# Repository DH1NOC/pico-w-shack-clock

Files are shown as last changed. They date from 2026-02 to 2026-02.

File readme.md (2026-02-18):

# Shack Präzisions-Weltzeituhr (Pico W)

Eine hochpräzise Amateurfunk-Stationsuhr auf Basis des Raspberry Pi Pico W. Sie kombiniert Internet-Zeit (NTP) mit einem temperaturkompensierten Echtzeit-Modul (DS3231) und visualisiert die Lokalzeit (MEZ/MESZ) sowie UTC parallel auf einem 2004 LCD-Display.

## Motivation & Konzept

Klassische Funkuhren auf **DCF77-Basis** stoßen in modernen Umgebungen oft an ihre Grenzen:

* **Empfangsprobleme:** Ferritstab-Antennen sind richtungsempfindlich; Signale werden in Gebäuden stark gedämpft.
* **Störanfälligkeit:** Schaltnetzteile, PCs und LED-Beleuchtung stören das Langwellensignal massiv.
* **Trägheit:** Ein vollständiger Zeitabgleich dauert nach dem Einschalten oft mehrere Minuten.
* **Fehlende UTC:** Handelsübliche Uhren zeigen meist nur die Lokalzeit, für den Funkbetrieb ist UTC jedoch essenziell.

**Die Lösung:**
Diese Uhr nutzt primär **NTP über WLAN** für die Genauigkeit und ein **RTC-Modul** für die Ausfallsicherheit.

* **Präzision:** Durch WLAN-Latenzen und MicroPython-Verarbeitung kann technisch ein Offset von ca. ±300ms auftreten. Dies ist für die visuelle Anzeige im Shack völlig akzeptabel.
* **Modularität:** Das integrierte GPS-Modul (GY-NEO6MV2) sorgt für Stratum-0-Präzision unabhängig vom Internet und ermöglicht die Anzeige des QTH-Locators.

---

## Hardware & Kosten

Die Gesamtkosten für das Projekt belaufen sich auf ca. **17€**.

### Teileliste

* **Mikrocontroller:** [Raspberry Pi Pico W (RP2040 WLAN)](https://www.berrybase.de/raspberry-pi-pico-w-rp2040-wlan-mikrocontroller-board)
* **GPS-Modul:** [u-blox NEO-6M / GY-NEO6MV2](https://amzn.eu/d/09GwwA2j)
* **RTC-Modul:** [DS3231 Real-Time Clock für Raspberry Pi](https://www.berrybase.de/ds3231-real-time-clock-modul-fuer-raspberry-pi)
* **Display (20x4 LCD mit I2C):**
* [Variante Weiß auf Blau](https://amzn.eu/d/08oH278n) oder
* [Variante Schwarz auf Grün](https://amzn.eu/d/0eiIwK74)

### Gehäuse (3D-Druck)

Es stehen zwei STL-Dateien für den Gehäusedruck zur Verfügung. Das Design ist so optimiert, dass **keine Stützen** notwendig sind:

* `Case_Front.stl` (Frontseite für Display und Pico)
* `Case_Back.stl` (Rückseite)

---

## Features

* **Timing:** Millisekunden-genaue Synchronisierung via GPS (Prio 1) oder NTP (Prio 2) mit Latenz-Korrektur.
* **Redundanz:** Dreistufiges Fallback-System: GPS -> WLAN/NTP -> DS3231 RTC.
* **Auto-Reconnect:** Automatische Wiederherstellung von WLAN und GPS-Fix im Hintergrund.
* **Smart Display (4 Zeilen):**
* Zeile 1: Datum, Wochentag und Callsign (rechtsbündig).
* Zeile 2: Lokalzeit (MEZ/MESZ).
* Zeile 3: UTC-Zeit.
* Zeile 4: Quelle (GPS/WLAN/RTC), bei GPS zusätzlich Satellitenanzahl & QTH Locator.

* **GPS-Integration:** Automatische Zeitsynchronisation und Positionsbestimmung (QTH Locator).
* **Debug-Modus:** Erweiterte Diagnose-Informationen für GPS und Systemstatus aktivierbar.
* **Boot-Animation:** Custom-Grafik eines Sendemasts mit Funkwellen beim Start.
* **Stabilität:** Modifizierter LCD-Treiber verhindert fehlerhafte Zeichen bei Soft-Resets.

---

## Verkabelung (Pinout)

Verwendet wird der I2C-Bus 0 des Pico W.

| Komponente | Pin | Pico W Pin | Farbe (Vorschlag) | Hinweis |
| --- | --- | --- | --- | --- |
| **DS3231 (RTC)** | VCC | **Pin 36 (3V3 OUT)** | Rot | 3.3V Versorgung |
|  | GND | **Pin 38 (GND)** | Schwarz | Masse |
|  | SDA | **Pin 1 (GP0)** | Blau | I2C Daten |
|  | SCL | **Pin 2 (GP1)** | Gelb | I2C Takt |
| **LCD 2004** | VCC | **Pin 40 (VBUS)** | Rot | **5V** (für Kontrast!) |
|  | GND | **Pin 3 (GND)** | Schwarz | Masse |
|  | SDA | **Pin 1 (GP0)** | Blau | Parallel zur RTC |
|  | SCL | **Pin 2 (GP1)** | Gelb | Parallel zur RTC |
| **GPS (NEO-6M)** | VCC | **Pin 40 (VBUS)** | Rot | 3.3-5V |
|  | GND | **Pin 38 (GND)** | Schwarz | Masse |
|  | TX | **Pin 7 (GP5)** | Grün | An Pico RX |
|  | RX | **Pin 6 (GP4)** | Weiß | An Pico TX |

> **Wichtig:** SDA und SCL von Display und RTC werden parallel auf dieselben Pins am Pico geführt.

---

## Einrichtung & Installation

### Schritt 1: MicroPython Firmware installieren

1. Aktuelle `.uf2`-Datei für Pico W laden: [micropython.org](https://micropython.org/download/RPI_PICO_W/)
2. Pico mit gedrückter **BOOTSEL**-Taste per USB anschließen.
3. Datei auf das erscheinende Laufwerk kopieren.

### Schritt 2: Entwicklungsumgebung

1. [Thonny IDE](https://thonny.org/) installieren.
2. Unten rechts als Interpreter **MicroPython (Raspberry Pi Pico)** wählen.

### Schritt 3: Dateien übertragen

Folgende Dateien müssen auf den Pico geladen werden:

* `lcd_api.py`: Basis-Treiber.
* `pico_i2c_lcd.py`: Modifizierter Treiber mit Reset-Fix.
* `config.json`: Konfigurationsdatei für WLAN.
* `main.py`: Hauptprogramm.

---

## Konfiguration (`config.json`)

Mehrere Netzwerke können als Fallback hinterlegt werden.

```json
{
    "wifi": [
        {
            "ssid": "MEIN_WLAN",
            "password": "PASSWORT1"
        },
        {
            "ssid": "BACKUP_WLAN",
            "password": "PASSWORT2"
        }
    ],
    "ntp_server": "pool.ntp.org",
    "sync_interval_min": 60
}

```

---

## Bedienung & Betrieb

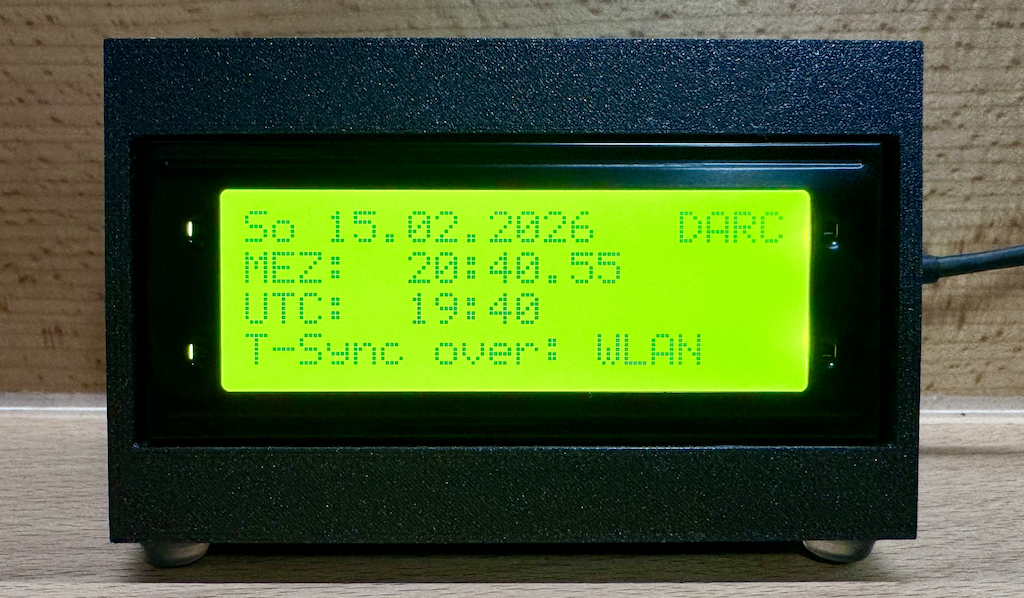
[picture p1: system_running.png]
System im Betrieb


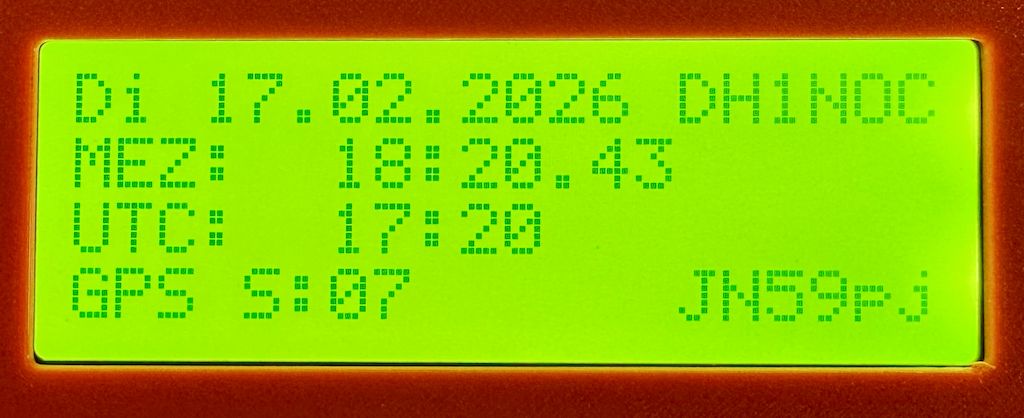
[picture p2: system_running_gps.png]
System im Betrieb mit GPS-Sync


1. **Start:** Strom anschließen (USB).
2. **Boot:** Die "DH1NOC CLOCK" Animation läuft (Sendemast strahlt Wellen ab).
3. **Betrieb:**
* Die Uhr startet sofort mit der Zeit aus dem **RTC-Modul** (Anzeige: `T-Sync over: RTC`).
* Im Hintergrund verbindet sie sich mit dem WLAN.
* Sobald verbunden, erfolgt der NTP-Abgleich. Die Anzeige wechselt auf `T-Sync over: WLAN`.
* Ein kleiner Stern `*` unten rechts signalisiert einen aktiven Abgleich.

4. **Ausfallsicherheit:** Sollte das WLAN ausfallen, läuft die Uhr präzise über das RTC-Modul weiter.

---

## Troubleshooting

* **Leeres Display:** Kontrast am blauen Potentiometer des I2C-Backpacks (Rückseite Display) justieren.
* **Kryptische Zeichen:** Pico kurz komplett stromlos machen (Hard Reset).
* **Falsche Stunde:** Die Zeitzone ist auf Deutschland fest voreingestellt. Prüfe die Funktion `get_cet_time_and_dst` in der `main.py`.

---

# Lizenz des Projekts

CC-BY-4.0
Dieses Projekt ist unter der [Creative Commons Attribution 4.0 International](https://creativecommons.org/licenses/by/4.0/deed.de) Lizenz lizenziert.

---

# Haftungsausschluss / Nutzung auf eigene Gefahr

Dieses Projekt wird ausschließlich zu Informations- und
Demonstrationszwecken bereitgestellt. Es handelt sich um ein
experimentelles Hobby- bzw. Entwicklungsprojekt und ausdrücklich **nicht
um ein geprüftes oder für den praktischen Einsatz geeignetes Produkt**.

Der Nachbau und die Nutzung erfolgen ausschließlich auf eigene
Verantwortung und Gefahr des Nutzers. Der Autor übernimmt keine Gewähr
für die Richtigkeit, Vollständigkeit, Funktionsfähigkeit oder Sicherheit
der bereitgestellten Informationen, Schaltungen, Software oder sonstigen
Inhalte.

## Haftung

Eine Haftung für Sachschäden, Vermögensschäden, Folgeschäden,
Produktionsausfälle, Datenverluste oder sonstige mittelbare Schäden ist
--- soweit gesetzlich zulässig --- ausgeschlossen.

## Fachkenntnisse erforderlich

Dieses Projekt richtet sich ausschließlich an Personen mit ausreichenden
Fachkenntnissen im Umgang mit Elektronik, elektrischen Anlagen und den
einschlägigen Sicherheitsvorschriften. Der Nutzer ist selbst
verantwortlich für die Einhaltung aller gesetzlichen Bestimmungen,
Normen und Sicherheitsanforderungen.

## Keine Produkthaftung

Es wird kein Produkt, keine Baugruppe und keine technische Lösung im
Sinne eines marktreifen Systems bereitgestellt. Es besteht kein
Vertragsverhältnis zwischen Autor und Nutzer.

## Sicherheitswarnung

Der Aufbau und Betrieb elektronischer Schaltungen kann zu Sachschäden,
Brand, elektrischem Schlag oder anderen Gefahren führen. Der Nachbau
darf nur erfolgen, wenn die sichere Funktion zweifelsfrei gewährleistet
werden kann.

## Salvatorische Klausel

Sollte eine Bestimmung dieses Haftungsausschlusses unwirksam sein oder
werden, bleibt die Wirksamkeit der übrigen Bestimmungen unberührt.

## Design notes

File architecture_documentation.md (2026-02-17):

# 🛠️ Projekt-Architektur: Shack-Weltzeituhr

Diese Dokumentation beschreibt den technischen Aufbau der Firmware für den Raspberry Pi Pico W. Das System ist modular gestaltet, um Hardware-Abhängigkeiten zu kapseln und die Systemstabilität bei Netzwerkausfällen zu gewährleisten.

---

## 1. System-Struktur

Der **Main Controller** (`main.py`) agiert als zentraler Koordinator zwischen den spezialisierten Layern:

* **Hardware Layer**: Zentralisierte Instanziierung der Treiber (I2C, UART).
* **Service Layer**: Abwicklung asynchroner Aufgaben wie NTP-Sync und WLAN-Management.
* **UI Layer**: Logikfreie Darstellung der Daten auf dem LCD 2004.

## 2. Dateistruktur

| Datei | Funktion |
| :--- | :--- |
| `main.py` | Einstiegspunkt; enthält die `ShackClock`-Klasse und den Main-Loop. |
| `hardware_manager.py` | Dependency-Injection Container für alle Hardware-Referenzen. |
| `time_synchronizer.py` | Entscheidungslogik der Zeitquellen-Kaskade (Priorisierung). |
| `display_manager.py` | LCD-Steuerung, Custom-Characters und Layout-Definition. |
| `qth_locator.py` | Algorithmus zur Konvertierung von GPS-Koordinaten in den QTH-Locator. |
| `time_utils.py` | Funktionen für MEZ/MESZ-Umrechnung und Zeitstempel-Korrektur. |
| `config.json` | Konfigurationsparameter für WLAN, NTP und Hardware-Optionen. |

## 3. Synchronisations-Strategie

Der `TimeSynchronizer` nutzt eine Prioritäten-Kaskade, um eine Stratum-0-nahe Präzision zu erreichen:

1.  **GPS (Priorität 1)**: Primärquelle bei gültigem Fix. Die Firmware kompensiert die Latenz zwischen NMEA-Empfang und Systemzeit-Update.
2.  **NTP (Priorität 2)**: Fallback bei fehlendem GPS-Fix und aktiver WLAN-Verbindung.
3.  **RTC (Priorität 3)**: Permanentes lokales Fundament durch das DS3231-Modul. Die RTC wird bei jedem erfolgreichen GPS/NTP-Sync abgeglichen, um Drift zu minimieren.

## 4. QTH-Locator Berechnung

Die Berechnung des 6-stelligen Locators erfolgt in der `qth_locator.py` basierend auf der aktuellen GPS-Position. Die Logik überführt Längen- und Breitengrade in Felder, Quadrate und Sub-Quadrate.

Die mathematische Basis für die Feld-Ermittlung (erste zwei Zeichen):

$$Feld_{Long} = \text{chr}\left(65 + \text{int}\left(\frac{Long + 180}{20}\right)\right)$$
$$Feld_{Lat} = \text{chr}\left(65 + \text{int}\left(\frac{Lat + 90}{10}\right)\right)$$

## 5. Performance & Echtzeit-Handling

Da MicroPython auf dem RP2040 Single-Core-zentriert arbeitet, wird ein striktes Polling-Verfahren genutzt:

* **GPS-Polling**: Der UART-Buffer wird alle 10ms geleert, um Datenverlust bei den NMEA-Sätzen zu verhindern.
* **Asynchrone Wartung**: WLAN-Reconnects und NTP-Abfragen blockieren nicht den Sekundenwechsel des Displays.
* **Stabilisierung**: Ein modifizierter LCD-Treiber unterdrückt fehlerhafte Zeichenbildungen bei Soft-Resets.

## 6. Diagnose (Debug-Modus)

Der über die `config.json` aktivierbare Debug-Modus (`"debug_mode": "GPS"`) dient der Feld-Analyse:

* Echtzeit-Anzeige der Roh-NMEA-Paketzähler.
* Visualisierung von Satellitenanzahl und Fix-Qualität (3D/2D).
* Direkter Abgleich der GPS-Koordinaten mit dem berechneten Locator.

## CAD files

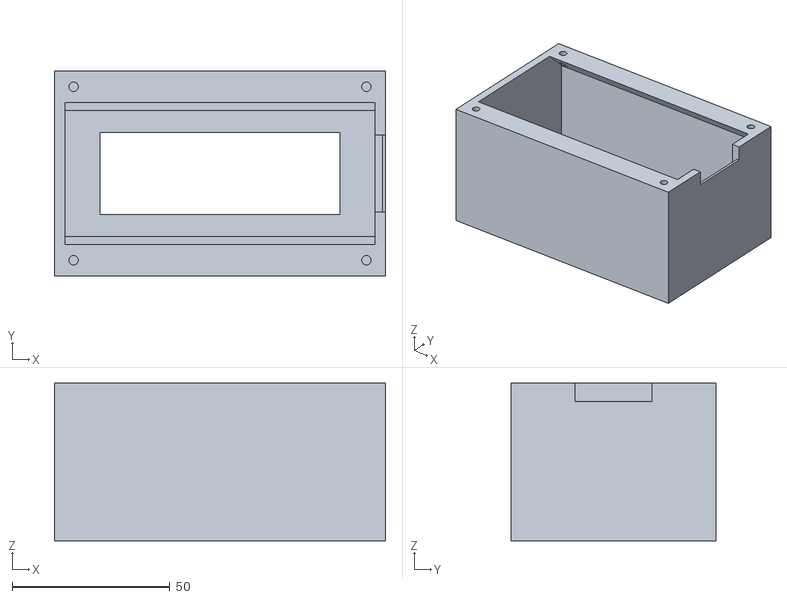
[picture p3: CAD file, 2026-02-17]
3D-Print-Files/Case for Display with Raspberry Pico - Front.stl
105.0 x 65.0 x 50.0

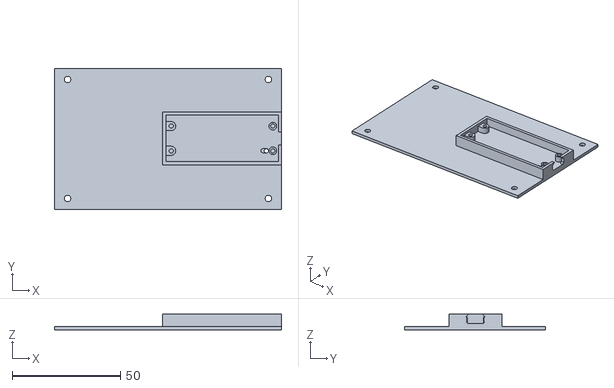
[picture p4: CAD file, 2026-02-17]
3D-Print-Files/Case for Display with Raspberry Pico Back.stl
105.0 x 65.0 x 7.30

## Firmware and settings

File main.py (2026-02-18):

"""
DH1NOC Shack Clock - Precision NTP-synchronized clock for Raspberry Pi Pico W
Version: 2.0 (Clean Code Refactored)
Author: DH1NOC
Features: GPS (Priority 1), NTP (Priority 2), RTC Fallback (Priority 3)
"""

import time
import json
from config import Config
from hardware_manager import HardwareManager
from time_synchronizer import TimeSynchronizer
from wifi_manager import WifiManager
from time_utils import TimeUtilities


class ShackClock:
    """Main application controller for precision timekeeping"""

    DISPLAY_UPDATE_INTERVAL_MS = 1000
    DISPLAY_UPDATE_INTERVAL_DEBUG_MS = 200
    GPS_POLL_INTERVAL_MS = 10
    MAIN_LOOP_SLEEP_MS = 20

    def __init__(self):
        self.config = self._load_configuration()
        self.debug_mode = self.config.get('debug_mode', Config.DEBUG_MODE)
        self.animation_counter = 0
        self.last_second = -1

        self._initialize_hardware()
        self._initialize_network()
        self._initialize_time_sync()

        if self.hardware.display:
            self.hardware.display.lcd.clear()

    def _load_configuration(self):
        """Load configuration from config.json"""
        try:
            with open('config.json', 'r') as f:
                return json.load(f)
        except Exception:
            return self._get_default_config()

    def _get_default_config(self):
        """Provide default configuration if file is missing"""
        return {
            "wifi": [],
            "ntp_server": Config.DEFAULT_NTP_SERVER,
            "sync_interval_min": Config.DEFAULT_SYNC_INTERVAL_MIN,
            "gps_enabled": Config.GPS_ENABLED,
            "debug_mode": Config.DEBUG_MODE
        }

    def _initialize_hardware(self):
        """Initialize all hardware components"""
        self.hardware = HardwareManager(self.config)
        self.hardware.initialize_all()

    def _initialize_network(self):
        """Initialize WiFi connection"""
        self.wifi = WifiManager()
        wifi_networks = self.config.get('wifi', [])

        if len(wifi_networks) > 0:
            first_network = wifi_networks[0]
            self.wifi.connect(first_network['ssid'], first_network['password'])

    def _initialize_time_sync(self):
        """Initialize time synchronization coordinator"""
        self.time_sync = TimeSynchronizer(
            self.hardware.get_gps(),
            self.hardware.get_ntp(),
            self.hardware.get_rtc(),
            self.hardware.get_display(),
            self.wifi
        )

        sync_interval = self.config.get('sync_interval_min', Config.DEFAULT_SYNC_INTERVAL_MIN)
        self.time_sync.set_ntp_interval(sync_interval)
        self.time_sync.load_rtc_time()

    def _update_display(self):
        """Update display based on current mode"""
        if not self.hardware.display:
            return

        if self._is_debug_mode():
            self._show_debug_screen()
        else:
            self._show_normal_screen()

    def _is_debug_mode(self):
        """Check if debug mode is active"""
        return self.debug_mode == Config.DEBUG_MODE_GPS

    def _show_debug_screen(self):
        """Display GPS debug information"""
        gps = self.hardware.get_gps()
        gps_status = gps.get_status() if gps else None
        self.hardware.display.show_gps_debug(gps_status, self.animation_counter)
        self.animation_counter += 1

    def _show_normal_screen(self):
        """Display normal time screen"""
        utc_time = time.gmtime()
        local_time, is_dst = TimeUtilities.get_cet_time_and_dst(utc_time)

        gps = self.hardware.get_gps()
        gps_status = gps.get_status() if gps else None
        time_source = self.time_sync.get_current_source()

        self.hardware.display.update_time_display(
            local_time, utc_time, is_dst, time_source, gps_status
        )

    def run(self):
        """Main application loop with time synchronization and display updates"""
        update_interval = self._get_display_update_interval()
        last_display_update = 0

        while True:
            self._poll_gps()

            now_ms = time.ticks_ms()

            if self._is_debug_mode():
                last_display_update = self._run_debug_mode(now_ms, last_display_update, update_interval)
                continue

            self._run_normal_mode()
            time.sleep_ms(self.MAIN_LOOP_SLEEP_MS)

    def _get_display_update_interval(self):
        """Get display update interval based on mode"""
        if self._is_debug_mode():
            return self.DISPLAY_UPDATE_INTERVAL_DEBUG_MS
        return self.DISPLAY_UPDATE_INTERVAL_MS

    def _poll_gps(self):
        """Poll GPS UART to prevent buffer overflow"""
        gps = self.hardware.get_gps()
        if gps:
            gps.update()

    def _run_debug_mode(self, now_ms, last_update, interval):
        """Run debug mode loop iteration

        Returns:
            int: Updated last_display_update timestamp
        """
        if time.ticks_diff(now_ms, last_update) >= interval:
            self._update_display()
            last_update = now_ms

        time.sleep_ms(self.GPS_POLL_INTERVAL_MS)
        return last_update

    def _run_normal_mode(self):
        """Run normal mode loop iteration"""
        current_second = time.gmtime()[5]

        if current_second != self.last_second:
            self.last_second = current_second
            self._update_display()
            self._maintain_network()
            self._synchronize_time()

    def _maintain_network(self):
        """Maintain WiFi connection"""
        wifi_networks = self.config.get('wifi', [])
        self.wifi.retry_if_needed(wifi_networks)

    def _synchronize_time(self):
        """Execute time synchronization"""
        self.time_sync.synchronize()


def main():
    """Application entry point"""
    clock = ShackClock()
    clock.run()


if __name__ == "__main__":
    main()

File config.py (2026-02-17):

"""
Hardware and application configuration constants
"""


class Config:
    """Central configuration for DH1NOC Shack Clock"""

    # I2C Bus Configuration
    I2C_ADDR = 0x27
    DS3231_ADDR = 0x68
    I2C_NUM = 0
    I2C_SDA_PIN = 0
    I2C_SCL_PIN = 1
    I2C_FREQ = 100000

    # LCD Display Configuration
    LCD_ROWS = 4
    LCD_COLS = 20

    # GPS Module Configuration (NEO-6M)
    GPS_UART_ID = 1
    GPS_TX_PIN = 4
    GPS_RX_PIN = 5
    GPS_BAUD = 9600
    GPS_ENABLED = True
    GPS_PRIORITY = 1

    # Localization
    WEEKDAYS = ["Mo", "Di", "Mi", "Do", "Fr", "Sa", "So"]

    # Network Configuration
    DEFAULT_NTP_SERVER = "pool.ntp.org"
    DEFAULT_SYNC_INTERVAL_MIN = 60
    WIFI_RETRY_INTERVAL_SEC = 300
    NTP_PRIORITY = 2

    # Timing Configuration
    NTP_SAMPLES = 3
    NTP_SAMPLE_DELAY_MS = 200
    RTC_SET_COMPENSATION_MS = 20
    RTC_PRIORITY = 3

    # Time Source Identifiers
    TIME_SOURCE_GPS = "GPS"
    TIME_SOURCE_NTP = "NTP"
    TIME_SOURCE_RTC = "RTC"

    # Debug Modes
    DEBUG_MODE = None
    DEBUG_MODE_GPS = "GPS"
    DEBUG_MODE_NTP = "NTP"
    DEBUG_MODE_WIFI = "WIFI"

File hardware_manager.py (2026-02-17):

"""
Hardware initialization and configuration manager
"""

from machine import I2C, Pin
from pico_i2c_lcd import I2cLcd
from config import Config
from ds3231 import DS3231
from gps_client import GPSClient
from ntp_client import NTPClient
from display_manager import DisplayManager


class HardwareManager:
    """Initialize and manage all hardware components"""
    
    def __init__(self, config_data):
        self.config = config_data
        self.i2c = None
        self.rtc = None
        self.display = None
        self.gps = None
        self.ntp = None
        
    def initialize_all(self):
        """Initialize all hardware components in correct order"""
        self._init_i2c()
        self._init_display()
        self._init_rtc()
        self._init_gps()
        self._init_ntp()
        
    def _init_i2c(self):
        """Initialize I2C bus"""
        self.i2c = I2C(
            Config.I2C_NUM,
            sda=Pin(Config.I2C_SDA_PIN),
            scl=Pin(Config.I2C_SCL_PIN),
            freq=Config.I2C_FREQ
        )
        
    def _init_display(self):
        """Initialize LCD display with boot animation"""
        try:
            lcd = I2cLcd(self.i2c, Config.I2C_ADDR, Config.LCD_ROWS, Config.LCD_COLS)
            callsign = self.config.get('callsign', 'DARC')
            self.display = DisplayManager(lcd, callsign)
            self.display.show_boot_animation()
        except Exception:
            self.display = None
            
    def _init_rtc(self):
        """Initialize DS3231 Real-Time Clock"""
        self.rtc = DS3231(self.i2c)
        
    def _init_gps(self):
        """Initialize GPS module if enabled"""
        if self.config.get('gps_enabled', Config.GPS_ENABLED):
            self.gps = GPSClient()
            
    def _init_ntp(self):
        """Initialize NTP client"""
        ntp_server = self.config.get('ntp_server', Config.DEFAULT_NTP_SERVER)
        self.ntp = NTPClient(ntp_server)
        
    def get_display(self):
        return self.display
    
    def get_rtc(self):
        return self.rtc
    
    def get_gps(self):
        return self.gps
    
    def get_ntp(self):
        return self.ntp

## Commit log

2026-02-15 Initial commit: Pico W Shack Clock mit NTP-Sync, RTC-Fallback und 3D-Gehäusedaten
2026-02-17 Version 2.0 mit GPS-Unterstützung
    [Case for Display with Raspberry Pico - Front.stl, Case for Display with Raspberry Pico Back.stl]
2026-02-17 Neues GPS-Sync-Bild zur Dokumentation hinzugefügt
    Das Bild "system_running_gps.png" wurde in die Dokumentation aufgenommen, um den Betriebszustand mit GPS-Synchronisation zu veranschaulichen. Es wurden keine Änderungen am Code vorgenommen.
2026-02-17 Versionsnummer auf 2.0 aktualisiert
    Die Software-Version wurde in display_manager.py und main.py auf 2.0 angehoben.
2026-02-18 Synchronisierungslogik verbessert
    Die TimeSynchronizer-Klasse verwendet nun eine intelligente Fallback-Logik für die Zeitquellen (GPS > NTP > RTC) und prüft die Aktualität der Synchronisierung. Die Methode _try_gps_sync wurde angepas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
    Die Auswahl und der Wechsel der Zeitquelle sind nun robuster und transparenter.
2026-02-18 NTP-Sync prüft WLAN; Haftungsausschluss ergänzt
    TimeSynchronizer prüft vor NTP-Synchronisation, ob WLAN verbunden ist, und überspringt den Sync bei fehlender Verbindung. Konstruktor entsprechend erweitert.
    In der readme.md wurde ein ausführlicher Haftungsausschluss zu Risiken und Haftung ergänzt.
2026-02-18 Haftungsausschluss und Lizenz im Readme überarbeitet
